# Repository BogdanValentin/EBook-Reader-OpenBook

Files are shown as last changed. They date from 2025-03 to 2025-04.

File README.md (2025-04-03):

# Proiect - OpenBook

## Diagrama Bloc

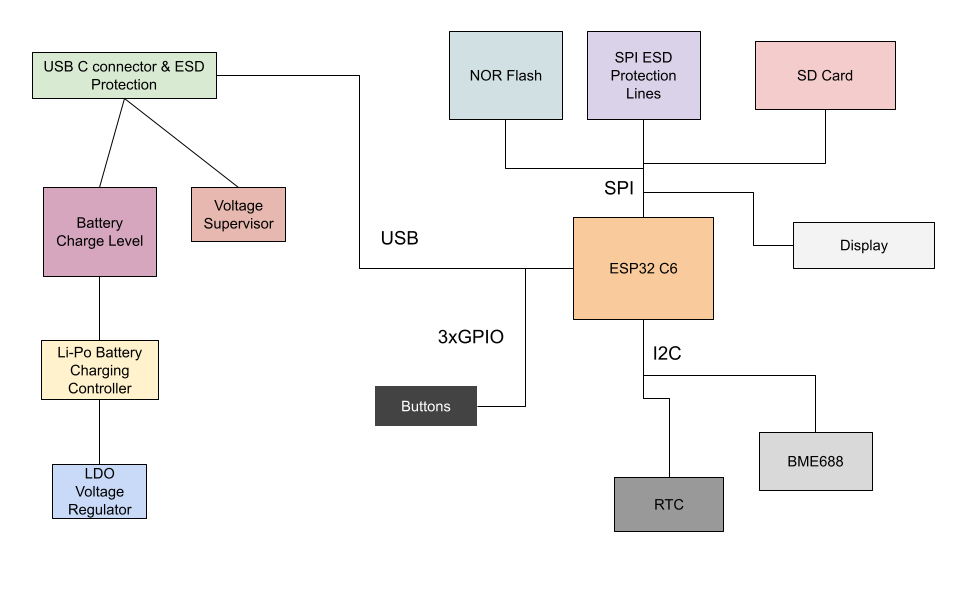
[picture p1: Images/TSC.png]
Diagrama Bloc
  

## Pasii de implementare
Am realizat in primul rand schema electrica propusa pe OCW. Apoi am realizat board-ul avand grija prima data sa tai placa dupa dimensiunile precizate. Am pus componentele pe placa incercand sa urmez designul propus. Am pus cele 2 planuri de masa si am rutat firele. Am creat modelele 3D pt placa, baterie si ecran si le-am asamblat in produsul finit.

## Probleme & decizii luate
Senzorul BME688 nu se afla in biblioteca ci BME680 asa ca l-am folosit pe acela. Apar mai multe erori la conectarea firelor GND to GND, am inteles ca mai multi se confrunta cu aceasta problema asa ca am lasat asa. Mufa USB creaza o eroare Board Outline Clearance care, la fel, am inteles ca este una comuna.

## Bill of Materials (BOM)

| Componenta | Link de Achizitie | Datasheet |
|---|---|---|
| **USB C connector** | [Link](https://ro.mouser.com/ProductDetail/GCT/USB4110-GF-A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) | [Datasheet](https://ro.mouser.com/datasheet/2/837/GCT_USB4110_Product_Drawing___20k_cycles-3455479.pdf) |
| **ESD Protection** | [Link](https://ro.mouser.com/ProductDetail/STMicroelectronics/USBLC6-2SC6Y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) | [Datasheet](https://ro.mouser.com/datasheet/2/389/usblc6_2sc6y-1852505.pdf) |
| **LDO Voltage Regulator** | [Link](https://ro.mouser.com/ProductDetail/Torex-Semiconductor/XC6220A331MR-G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) | [Datasheet](https://ro.mouser.com/datasheet/2/760/xc6220-3371556.pdf) |
| **SD Card** | [Link](https://store.comet.srl.ro/Catalogue/Product/43497/?mark=2) | [Datasheet](https://www.attend.com.tw/data/download/file/112A-TAAR-R03.rar) |
| **ESP32 C6** | [Link](https://ro.mouser.com/ProductDetail/Espressif-Systems/ESP32-C6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) | [Datasheet](https://ro.mouser.com/datasheet/2/891/esp32_c6_datasheet_en-3304070.pdf) |
| **Li-Po Battery Charging Controller**| [Link](https://ro.mouser.com/ProductDetail/Microchip-Technology/MCP73831-2ATI-MC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) | [Datasheet](https://ro.mouser.com/datasheet/2/268/MCP73831_Family_Data_Sheet_DS20001984H-3441711.pdf) | |
| **E-Paper Drive Circuit** | [Link](https://ro.mouser.com/ProductDetail/Vishay-Semiconductors/SI1308EDL-T1-GE3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) | [Datasheet](https://www.vishay.com/doc?63399) |
| **E-Paper Display Header** | [Link](https://ro.mouser.com/ProductDetail/Hirose-Connector/FH34SRJ-24S-0.5SH99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) | [Datasheet](https://ro.mouser.com/datasheet/2/185/FH34SRJ_24S_0_5SH_99__CL0580_1255_6_99_2DDrawing_0-1615044.pdf) |
| **EPD Power** | [Link](https://ro.mouser.com/ProductDetail/Diodes-Incorporated/DMG2305UX-7?qs=L1DZKBg7t5F%2FNBHrjfxC%252Bg%3D%3D) | [Datasheet](https://www.diodes.com/assets/Datasheets/DMG2305UX.pdf) |
| **Environmental Sensor BME688** | [Link](https://ro.mouser.com/ProductDetail/Bosch-Sensortec/BME688?qs=IS%252B4QmGtzzqQoVDscqwx3A%3D%3D) | [Datasheet](https://ro.mouser.com/datasheet/2/783/bst_bme688_fl000-2307034.pdf) |
| **Voltage Supervisor** | [Link](https://ro.mouser.com/ProductDetail/ROHM-Semiconductor/BD5229G-TR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) | [Datasheet](https://fscdn.rohm.com/en/products/databook/datasheet/ic/power/voltage_detector/bd52xxg-e.pdf) |
| **Battery Charge Level** | [Link](https://ro.mouser.com/ProductDetail/Analog-Devices-Maxim-Integrated/MAX17048G+T10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) | [Datasheet](https://ro.mouser.com/datasheet/2/609/MAX17048_MAX17049-3469099.pdf) |
| **RTC Module DS3231SN** | [Link](https://ro.mouser.com/ProductDetail/Analog-Devices-Maxim-Integrated/DS3231SNTR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) | [Datasheet](https://ro.mouser.com/datasheet/2/609/DS3231-3421123.pdf) | | |
| **SPI ESD Protection Lines** | [Link](https://ro.mouser.com/ProductDetail/Littelfuse/PGB1010603MR?qs=gu7KAQ731URLg4GSnNNN7Q%3D%3D) | [Datasheet](https://www.littelfuse.com/assetdocs/pulseguard-esd-suppressors-pgb1-datasheet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) |
| **External NORFlash 64MB** | [Link](https://ro.mouser.com/ProductDetail/Winbond/W25Q512JVEIQ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) | [Datasheet](https://ro.mouser.com/datasheet/2/949/Winbond_W25Q512JV_Datasheet-3240039.pdf) |

---

## 3. Descrierea Functionalitatii Hardware

## Componente Folosite:

1. **USB C connector & ESD protection**  
2. **LDO Voltage Regulator**  
3. **SD card**  
4. **ESP32 C6**  
5. **Li-Po Battery Charging Controller**  
6. **Display Type Selector**  
7. **E-Paper Drive Circuit**  
8. **E-Paper Display Header**  
9. **EPD Power**  
10. **Environmental Sensor BME688**  
11. **Voltage Supervisor + Reset & Boot/IO Button**  
12. **Battery ChargeLevel**  
13. **RTC Module DS3231SN**  
14. **Qwiic/Stemma QT**  
15. **Test Pads**  
16. **SPI ESD Protection Lines**  
17. **External NORFlash 64MB**

---

## 4. ESP32-C6 Pini

| Componenta | Pini ESP32 | Rol |
|---|---|---|
| **E-Paper Display** | SPI (MISO, MOSI, CLK, CS) | Afisare |
| **BME688** | I2C (SDA, SCL) | Senzor multirol |
| **RTC DS3231SN** | I2C (SDA, SCL) | Ceas / Temporizare  |
| **Li-Po Battery Controller** | GPIO  | incarcare |
| **SD Card** | SPI (MISO, MOSI, CLK, CS) | Stocare date |
| **Qwiic/Stemma QT** | I2C | -  |

---

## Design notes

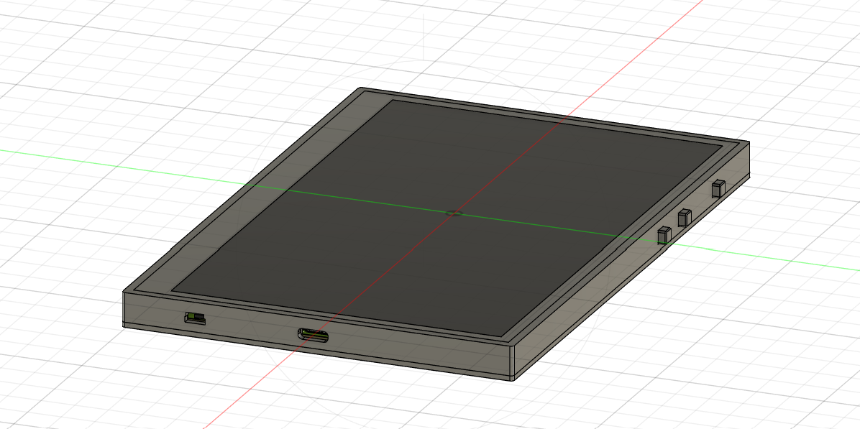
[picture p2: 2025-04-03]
Images/carcasa.png

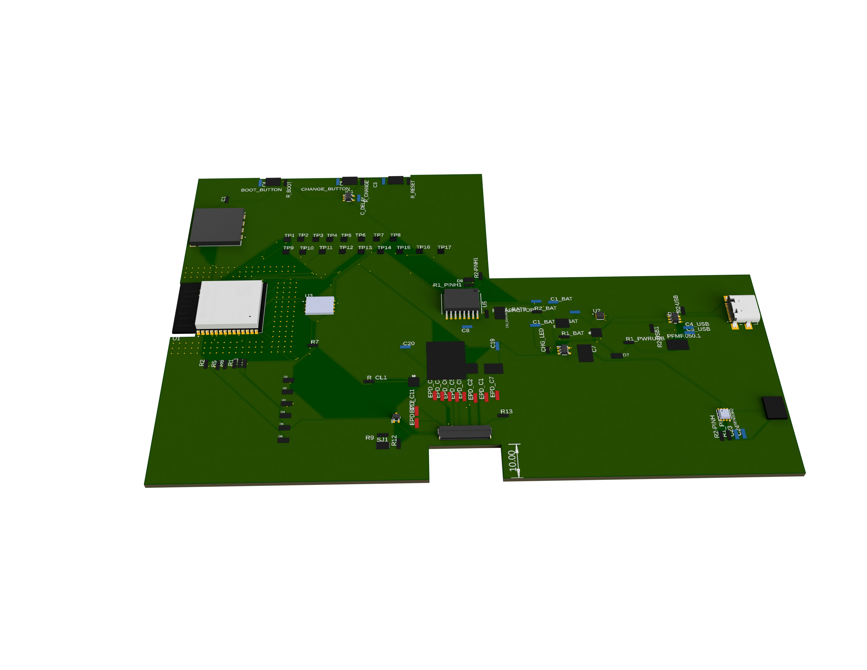
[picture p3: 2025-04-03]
Images/pcb.PNG

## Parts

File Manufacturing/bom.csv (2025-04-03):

Qty | Value | Device | Package | Parts | Description | ARROW_PART_NUMBER | ARROW_PRICE-STOCK | AVAILABILITY | CENTROID_NOT_SPECIFIED | CHECK_PRICES | COPYRIGHT | DATASHEET | DESCRIPTION | DIGIKEY_DESCRIPTION | DIGIKEY_PART_NUMBER | HEIGHT | LEAD_FREE | MANUFACTURER_NAME | MANUFACTURER_PART_NUMBER | MF | MFR_NAME | MOUSER_PART_NUMBER | MOUSER_PRICE-STOCK | MOUSER_TESTING_PART_NUMBER | MOUSER_TESTING_PRICE-STOCK | MP | MPN | PACKAGE | POPULARITY | PREFIX | PRICE | PROD_ID | PURCHASE-URL | ROHS | SNAPEDA_LINK | SPICEMODEL | SPICEPREFIX | TEMPERATURE_RANGE_HIGH | TEMPERATURE_RANGE_LOW | TP_SIGNAL_NAME | VALUE
1 |  | ADAFRUIT_LEDCHIP-LED0603 | ADAFRUIT_CHIP-LED0603 | CHG_LED | LED
3 |  | BUTTON_CUSYOMV1 | MYBUTTON | BOOT_BUTTON, CHANGE_BUTTON, RESET_BUTTON
1 |  | ESP32_WROVER_EAGLE-LTSPICE_RR0402 | ESP32_WROVER_EAGLE-LTSPICE_R0402 | R9 | RESISTOR, European symbol |  |  |  |  |  |  |  |  |  |  |  |  |  |  |  |  |  |  |  |  |  |  |  |  |  |  |  |  |  |  | NONE | R
1 |  | SJ | SJ | SJ1 | SMD solder JUMPER |  |  |  |  |  |  |  |  |  |  |  |  |  |  |  |  |  |  |  |  |  |  |  | 3
1 | 0.47 | ESP32_WROVER_EAGLE-LTSPICE_RR0402 | ESP32_WROVER_EAGLE-LTSPICE_R0402 | R12 | RESISTOR, European symbol |  |  |  |  |  |  |  |  |  |  |  |  |  |  |  |  |  |  |  |  |  |  |  |  |  |  |  |  |  |  | NONE | R
1 | 100K | ESP32_WROVER_EAGLE-LTSPICE_RR0402 | ESP32_WROVER_EAGLE-LTSPICE_R0402 | R1_PWRUSB | RESISTOR, European symbol |  |  |  |  |  |  |  |  |  |  |  |  |  |  |  |  |  |  |  |  |  |  |  |  |  |  |  |  |  |  | NONE | R
8 | 100nF | EAGLE-LTSPICE_CC0402 | EAGLE-LTSPICE_C0402 | C1, C4, C4_USB, C5, C8, C23, C24, C_DELAY | CAPACITOR, European symbol |  |  |  |  |  |  |  |  |  |  |  |  |  |  |  |  |  |  |  |  |  |  |  |  |  |  |  |  |  |  | NONE | C
1 | 100uF TANT | RCL_CPOL-EUCT3528 | RCL_CT3528 | C7 | POLARIZED CAPACITOR, European symbol |  |  |  |  |  |  |  |  |  |  |  |  |  |  |  |  |  |  |  |  |  |  |  | 0 |  |  |  |  |  |  |  | C
13 | 10K | ESP32_WROVER_EAGLE-LTSPICE_RR0402 | ESP32_WROVER_EAGLE-LTSPICE_R0402 | R1, R1_PINH, R2, R2-PINH, R3, R4, R5, R6, R7, R13, R_BOOT, R_CL1, R_RESET | RESISTOR, European symbol |  |  |  |  |  |  |  |  |  |  |  |  |  |  |  |  |  |  |  |  |  |  |  |  |  |  |  |  |  |  | NONE | R
3 | 10k | ESP32_WROVER_EAGLE-LTSPICE_RR0402 | ESP32_WROVER_EAGLE-LTSPICE_R0402 | R1_PINH1, R2-PINH1, R_CHANGE | RESISTOR, European symbol |  |  |  |  |  |  |  |  |  |  |  |  |  |  |  |  |  |  |  |  |  |  |  |  |  |  |  |  |  |  | NONE | R
1 | 10uF | EAGLE-LTSPICE_CC0402 | EAGLE-LTSPICE_C0402 | C20 | CAPACITOR, European symbol |  |  |  |  |  |  |  |  |  |  |  |  |  |  |  |  |  |  |  |  |  |  |  |  |  |  |  |  |  |  | NONE | C
1 | 112A-TAAR-R03_ATTEND | 112A-TAAR-R03_ATTEND | 112ATAARR03ATTEND | J1 | Micro SD Card Socket, Push-Push Type, Top Mount, SMT, H=1.83mm, 10u |  |  |  |  |  |  |  | Micro SD Card Socket | Push-Push Type | Top Mount | SMT | H=1.83mm | 10u |  |  | 1.9mm |  | ATTEND | 112A-TAAR-R03 ATTEND
1 | 15 | ESP32_WROVER_EAGLE-LTSPICE_RR0402 | ESP32_WROVER_EAGLE-LTSPICE_R0402 | R_CAPACITOR | RESISTOR, European symbol |  |  |  |  |  |  |  |  |  |  |  |  |  |  |  |  |  |  |  |  |  |  |  |  |  |  |  |  |  |  | NONE | R
1 | 1uF | EAGLE-LTSPICE_CC0402 | EAGLE-LTSPICE_C0402 | C3 | CAPACITOR, European symbol |  |  |  |  |  |  |  |  |  |  |  |  |  |  |  |  |  |  |  |  |  |  |  |  |  |  |  |  |  |  | NONE | C
10 | 1uF/50V | EAGLE-LTSPICE_CC0402 | EAGLE-LTSPICE_C0402 | EPD_C1, EPD_C2, EPD_C5, EPD_C6, EPD_C7, EPD_C8, EPD_C9, EPD_C10, EPD_C11, EPD_C12 | CAPACITOR, European symbol |  |  |  |  |  |  |  |  |  |  |  |  |  |  |  |  |  |  |  |  |  |  |  |  |  |  |  |  |  |  | NONE | C
1 | 200 | ESP32_WROVER_EAGLE-LTSPICE_RR0402 | ESP32_WROVER_EAGLE-LTSPICE_R0402 | R1_BAT | RESISTOR, European symbol |  |  |  |  |  |  |  |  |  |  |  |  |  |  |  |  |  |  |  |  |  |  |  |  |  |  |  |  |  |  | NONE | R
2 | 20V/4.2A/52mO/1.4W | ESP32_WROVER_SPARKFUN-DISCRETESEMI_MOSFET_PCH-DMG2305UX-7 | ESP32_WROVER_SPARKFUN-DISCRETESEMI_SOT23-3 | Q1, Q2 | P-channel MOSFETs |  |  |  |  |  |  |  |  |  |  |  |  |  |  |  |  |  |  |  |  |  |  |  |  |  |  | TRAN-14388 |  |  |  |  |  |  |  |  | 20V/4.2A/52mO/1.4W
1 | 2K | ESP32_WROVER_EAGLE-LTSPICE_RR0402 | ESP32_WROVER_EAGLE-LTSPICE_R0402 | R2_BAT | RESISTOR, European symbol |  |  |  |  |  |  |  |  |  |  |  |  |  |  |  |  |  |  |  |  |  |  |  |  |  |  |  |  |  |  | NONE | R
4 | 4.7uF | EAGLE-LTSPICE_CC0402 | EAGLE-LTSPICE_C0402 | C1_BAT, C1_BAT1, C1_BAT2, C5_USB | CAPACITOR, European symbol |  |  |  |  |  |  |  |  |  |  |  |  |  |  |  |  |  |  |  |  |  |  |  |  |  |  |  |  |  |  | NONE | C
1 | 4.7uF | EAGLE-LTSPICE_CC0402 | EAGLE-LTSPICE_C0402 | C2_BAT | CAPACITOR, European symbol |  |  |  |  |  |  |  |  |  |  |  |  |  |  |  |  |  |  |  |  |  |  |  |  |  |  |  |  |  |  | NONE | C
1 | 4.7uF/25V | EAGLE-LTSPICE_CC0402 | EAGLE-LTSPICE_C0402 | C19 | CAPACITOR, European symbol |  |  |  |  |  |  |  |  |  |  |  |  |  |  |  |  |  |  |  |  |  |  |  |  |  |  |  |  |  |  | NONE | C
2 | 5k1 | ESP32_WROVER_EAGLE-LTSPICE_RR0402 | ESP32_WROVER_EAGLE-LTSPICE_R0402 | R2-USB, R2-USB1 | RESISTOR, European symbol |  |  |  |  |  |  |  |  |  |  |  |  |  |  |  |  |  |  |  |  |  |  |  |  |  |  |  |  |  |  | NONE | R
1 | 68uH | 744043680IND_4828-WE-TPC_WRE | IND_4828-WE-TPC_WRE | L1 |  |  |  |  |  |  | Copyright (C) 2024 Ultra Librarian. All rights reserved. |  |  |  |  |  |  |  | 744043680 |  | Wurth Electronics
1 | BD5229G-TR | BD5229G-TR | SOT95P280X125-5N | IC1 | Voltage Detector with Adjustable Delay Time: CMOS processes are utilized to develop high precision, low current consumption CMOS reset ICs that allow arbitrary setting of the delay time. The extensive lineup includes both Nch Open Drain and CMOS output types in a wide range of detection voltages (from 2.3V to 6.0V, in 0.1V steps), enabling selection of the ideal solution based on customer requirements. In addition, the entire series is of course both lead-free and RoHS-compliant. |  |  |  |  |  |  |  | Voltage Detector with Adjustable Delay Time: CMOS processes are utilized to develop high precision | low current consumption CMOS reset ICs that allow arbitrary setting of the delay time. The extensive lineup includes both Nch Open Drain and CMOS output types in a wide range of detection voltages (from 2.3V to 6.0V | in 0.1V steps) | enabling selection of the ideal solution based on customer requirements. In addition | the entire series is of course both lead-free and RoHS-compliant. |  |  | 1.25mm |  | ROHM Semiconductor | BD5229G-TR |  |  | 755-BD5229G-TR | https://www.mouser.co.uk/ProductDetail/ROHM-Semiconductor/BD5229G-TR?qs=4kLU8WoGk0vvnhrrYwdszw%3D%3D
1 | CPH3225A | CPH3225A | CAPCP3225X100N | C10_SUPERCAP | Cap 0.011F 3.3V 1210 Flat Check availability |  |  | Not in stock |  | https://www.snapeda.com/parts/CPH3225A/Seiko+Instruments/view-part/?ref=eda |  |  | 11 mF (EDLC) Supercapacitor 3.3 V 1210 (3225 Metric) - - |  |  |  |  |  |  | Seiko Instruments |  |  |  |  |  | CPH3225A |  | 1210 Seiko |  |  | None |  | https://www.snapeda.com/api/url_track_click_mouser/?unipart_id=562593&manufacturer=Seiko Instruments&part_name=CPH3225A&search_term=None |  | https://www.snapeda.com/parts/CPH3225A/Seiko+Instruments/view-part/?ref=snap
1 | DS3231SN# | DS3231SN# | SOIC127P1032X265-16N | U5 | Real Time Clock Serial 16-Pin SOIC W T/R Check availability |  |  | In Stock |  | https://www.snapeda.com/parts/DS3231SN%23/Analog+Devices/view-part/?ref=eda |  |  | Extremely Accurate I²C-Integrated RTC/TCXO/Crystal |  |  |  |  |  |  | Analog Devices |  |  |  |  |  | DS3231SN# |  | SOIC-16 Maxim |  |  | None |  | https://www.snapeda.com/api/url_track_click_mouser/?unipart_id=99048&manufacturer=Analog Devices&part_name=DS3231SN#&search_term=None |  | https://www.snapeda.com/parts/DS3231SN%23/Analog+Devices/view-part/?ref=snap
1 | ESP32-C6-WROOM-1-N8 | ESP32-C6-WROOM-1-N8 | XCVR_ESP32-C6-WROOM-1-N8 | U1 | Check availability |  |  | In Stock |  | https://www.snapeda.com/parts/ESP32-C6-WROOM-1-N8/Espressif+Systems/view-part/?ref=eda |  |  | Multiprotocol Modules ESP32-C6 module | Wi-Fi 6 in 2.4 GHz band | Bluetooth 5 | Zigbee 3.0 and Thread. ESP34-WROOM Compatible - ENGINEERING SAMPLE |  |  |  |  |  |  | Espressif Systems |  |  |  |  |  | ESP32-C6-WROOM-1-N8 |  | None |  |  | None |  |  |  | https://www.snapeda.com/parts/ESP32-C6-WROOM-1-N8/Espressif+Systems/view-part/?ref=snap
1 | ESP32C6_VARISTORCN1812 | ESP32C6_VARISTORCN1812 | ESP32C6_VARISTOR_CT/CN1812 | PFMF.050.1 | VARISTOR |  |  |  |  |  |  |  |  |  |  |  |  |  |  |  |  |  |  |  |  |  |  |  | 0
2 | ESP32_WROVER_AVX---SD0805S020S1R0_AVX_SD0805S020S1R0_0_0AVX_SD0805S020S1R0_0_0 | ESP32_WROVER_AVX---SD0805S020S1R0_AVX_SD0805S020S1R0_0_0AVX_SD0805S020S1R0_0_0 | ESP32_WROVER_AVX---SD0805S020S1R0_AVX_SD0805S020S1R0_0 | D7, D8 | Schottky Barrier Rectifier Diode |  |  |  | No |  |  | http://datasheets.avx.com/schottky.pdf |  | DIODE SCHOTTKY 20V 1A 0805 | 478-7800-1-ND |  | yes |  |  | AVX |  | 581-SD0805S020S1R0 |  |  |  |  |  | 0805 (2012 metric) |  | D |  |  |  | yes |  |  |  | +125°C | -55°C
1 | ESP32_WROVER_BME680_BME680 | ESP32_WROVER_BME680_BME680 | ESP32_WROVER_BME680_PSON80P300X300X100-8N | SENSOR2 | Integrated Environmental Unit |  |  | Unavailable |  |  |  |  | Integrated Environmental Unit |  |  |  |  |  |  | Bosch Sensortec |  |  |  |  |  | BME680 |  | LGA-8 Bosch Tools |  |  | None
1 | ESP32_WROVER_SPARKFUN-IC-POWER_MCP73831 | ESP32_WROVER_SPARKFUN-IC-POWER_MCP73831 | ESP32_WROVER_SPARKFUN-IC-POWER_SOT23-5 | U4 | MCP73831T Li-Ion, Li-Pol Controller |  |  |  |  |  |  |  |  |  |  |  |  |  |  |  |  |  |  |  |  |  |  |  |  |  |  | IC-09995
1 | FH34SRJ-24S-0.5SH_99_ | FH34SRJ-24S-0.5SH_99_ | FH34SRJ24S05SH99 | J3 | (0.50mm) Surface Mount, Right Angle |  |  |  |  |  |  |  | 24 Position FFC | FPC Connector Contacts | (0.50mm) Surface Mount | Right Angle |  |  | 1.1mm |  | Hirose | FH34SRJ-24S-0.5SH(99) |  |  | 798-FH34SRJ24S05SH99 | https://www.mouser.co.uk/ProductDetail/Hirose-Connector/FH34SRJ-24S-0.5SH99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
1 | MAX17048G+T10 | MAX17048G+T10 | SON50P200X200X80-9N | U2 | Check availability |  |  | In Stock |  | https://www.snapeda.com/parts/MAX17048G+T10/Analog+Devices/view-part/?ref=eda |  |  | 3µA 1-Cell/2-Cell Fuel Gauge with ModelGauge |  |  |  |  |  |  | Analog Devices |  |  |  |  |  | MAX17048G+T10 |  | TDFN-8 Maxim |  |  | None |  | https://www.snapeda.com/api/url_track_click_mouser/?unipart_id=329239&manufacturer=Analog Devices&part_name=MAX17048G+T10&search_term=None |  | https://www.snapeda.com/parts/MAX17048G+T10/Analog+Devices/view-part/?ref=snap
3 | MBR0530 | MBR0530 | SOD3716X135N | D9, D10, D11 | ON SEMICONDUCTOR - MBR0530 - DIODE, SCHOTTKY, 0.5A, 30V, SOD-123 |  |  | In Stock |  | https://www.snapeda.com/parts/MBR0530/Onsemi/view-part/?ref=eda |  |  | Diode Schottky 30 V 500mA Surface Mount SOD-123 |  |  |  |  |  |  | ON Semiconductor |  |  |  |  |  | MBR0530 |  | SOD-123-2 ON Semiconductor |  |  | None |  | https://www.snapeda.com/api/url_track_click_mouser/?unipart_id=179458&manufacturer=ON Semiconductor&part_name=MBR0530&search_term=None |  | https://www.snapeda.com/parts/MBR0530/Onsemi/view-part/?ref=snap
6 | PGB1010603MR | PGB1010603MR | DIOC1608X36N | D1, D2, D3, D4, D5, D6 | Check availability |  |  | In Stock |  | https://www.snapeda.com/parts/PGB1010603MR/Littelfuse/view-part/?ref=eda |  |  | 150V (Typ) Clamp - Ipp Tvs Diode Surface Mount 0603 (1608 Metric) |  |  |  |  |  |  | Littelfuse Inc. |  |  |  |  |  | PGB1010603MR |  | 0603 Littelfuse Inc. |  |  | None |  | https://www.snapeda.com/api/url_track_click_mouser/?unipart_id=5659453&manufacturer=Littelfuse Inc.&part_name=PGB1010603MR&search_term=None |  | https://www.snapeda.com/parts/PGB1010603MR/Littelfuse/view-part/?ref=snap
1 | QWIIC_RIGHT_ANGLE | QWIIC_CONNECTORJS-1MM | JST04_1MM_RA | J2 | SparkFun I2C Standard Qwiic Connector |  |  |  |  |  |  |  |  |  |  |  |  |  |  |  |  |  |  |  |  |  |  |  |  |  |  | CONN-13694 |  |  |  |  |  |  |  |  | QWIIC_RIGHT_ANGLE
1 | SAMACSYS_PARTS_USB4110-GF-A | SAMACSYS_PARTS_USB4110-GF-A | SAMACSYS_PARTS_USB4110GFA | J4 | CONN USB 2.0 TYPE-C R/A SMT |  |  |  |  |  |  |  | CONN USB 2.0 TYPE-C R/A SMT |  |  | 3.26mm |  | GCT (GLOBAL CONNECTOR TECHNOLOGY) | USB4110-GF-A |  |  | 640-USB4110-GF-A | https://www.mouser.co.uk/ProductDetail/GCT/USB4110-GF-A?qs=KUoIvG%2F9IlYiZvIXQjyJeA%3D%3D
1 | SI1308EDL-T1-GE3 | SI1308EDL-T1-GE3 | SOT65P210X110-3N | Q3 | MOSFET N-Ch 30V 1.5A TrenchFET SC70 Vishay Si1308EDL-T1-GE3 N-channel MOSFET Transistor, 1.5 A, 30 V, 3-Pin SC-70 |  |  | In Stock |  | https://www.snapeda.com/parts/SI1308EDL-T1-GE3/Vishay+Siliconix/view-part/?ref=eda |  |  | Si1308EDL-T1-GE3 N-channel MOSFET Transistor | 1.5 A | 30 V | 3-Pin SC-70 | Siliconix / Vishay SI1308EDL-T1-GE3 |  |  |  |  |  |  | Vishay Siliconix |  |  |  |  |  | SI1308EDL-T1-GE3 |  | SOT-323 Vishay Semiconductor |  |  | None |  | https://www.snapeda.com/api/url_track_click_mouser/?unipart_id=274603&manufacturer=Vishay Siliconix&part_name=SI1308EDL-T1-GE3&search_term=None |  | https://www.snapeda.com/parts/SI1308EDL-T1-GE3/Vishay+Siliconix/view-part/?ref=snap
17 | TPTP20R | TPTP20R | TP20R | TP1, TP2, TP3, TP4, TP5, TP6, TP7, TP8, TP9, TP10, TP11, TP12, TP13, TP14, TP15, TP16, TP17 | Test pad |  |  |  |  |  |  |  |  |  |  |  |  |  |  |  |  |  |  |  |  |  |  |  | 2
1 | USBLC6-2SC6Y | USBLC6-2SC6Y | SOT95P280X145-6N | D12 | Low Cap. ESD Protection Auto SOT-23-6 STMicroelectronics USBLC6-2SC6Y, Dual Uni-Directional TVS Diode Array, 6-Pin SOT-23 |  |  | In Stock |  | https://www.snapeda.com/parts/USBLC6-2SC6Y/STMicroelectronics/view-part/?ref=eda |  |  | 17V Clamp 5A (8/20µs) Ipp Tvs Diode Surface Mount SOT-23-6 |  |  |  |  |  |  | STMicroelectronics |  |  |  |  |  | USBLC6-2SC6Y |  | SOT-23-6 STMicroelectronics |  |  | None |  |  |  | https://www.snapeda.com/parts/USBLC6-2SC6Y/STMicroelectronics/view-part/?ref=snap
1 | W25Q512JVEIQ | W25Q512JVEIQ | SON127P600X800X80-9N | U3 | Check availability |  |  | In Stock |  | https://www.snapeda.com/parts/W25Q512JVEIQ/Winbond+Electronics/view-part/?ref=eda |  |  | FLASH - NOR Memory IC 512Mb (64M x 8) SPI - Quad I/O 133 MHz 8-WSON (8x6) |  |  |  |  |  |  | Winbond Electronics |  |  |  |  |  | W25Q512JVEIQ |  | Package |  |  | None |  |  |  | https://www.snapeda.com/parts/W25Q512JVEIQ/Winbond+Electronics/view-part/?ref=snap
1 | XC6220A331MR-G | XC6220A331MR-G | SOT95P280X120-5N | IC2 | LDO Voltage Regulators |  |  |  |  |  |  |  | LDO Voltage Regulators |  |  | 1.2mm |  | Torex | XC6220A331MR-G |  |  | 865-XC6220A331MR-G | https://www.mouser.co.uk/ProductDetail/Torex-Semiconductor/XC6220A331MR-G?qs=AsjdqWjXhJ8ZSWznL1J0gg%3D%3D

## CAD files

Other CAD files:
Mechanical/OpenBook Enclosure v7.f3z

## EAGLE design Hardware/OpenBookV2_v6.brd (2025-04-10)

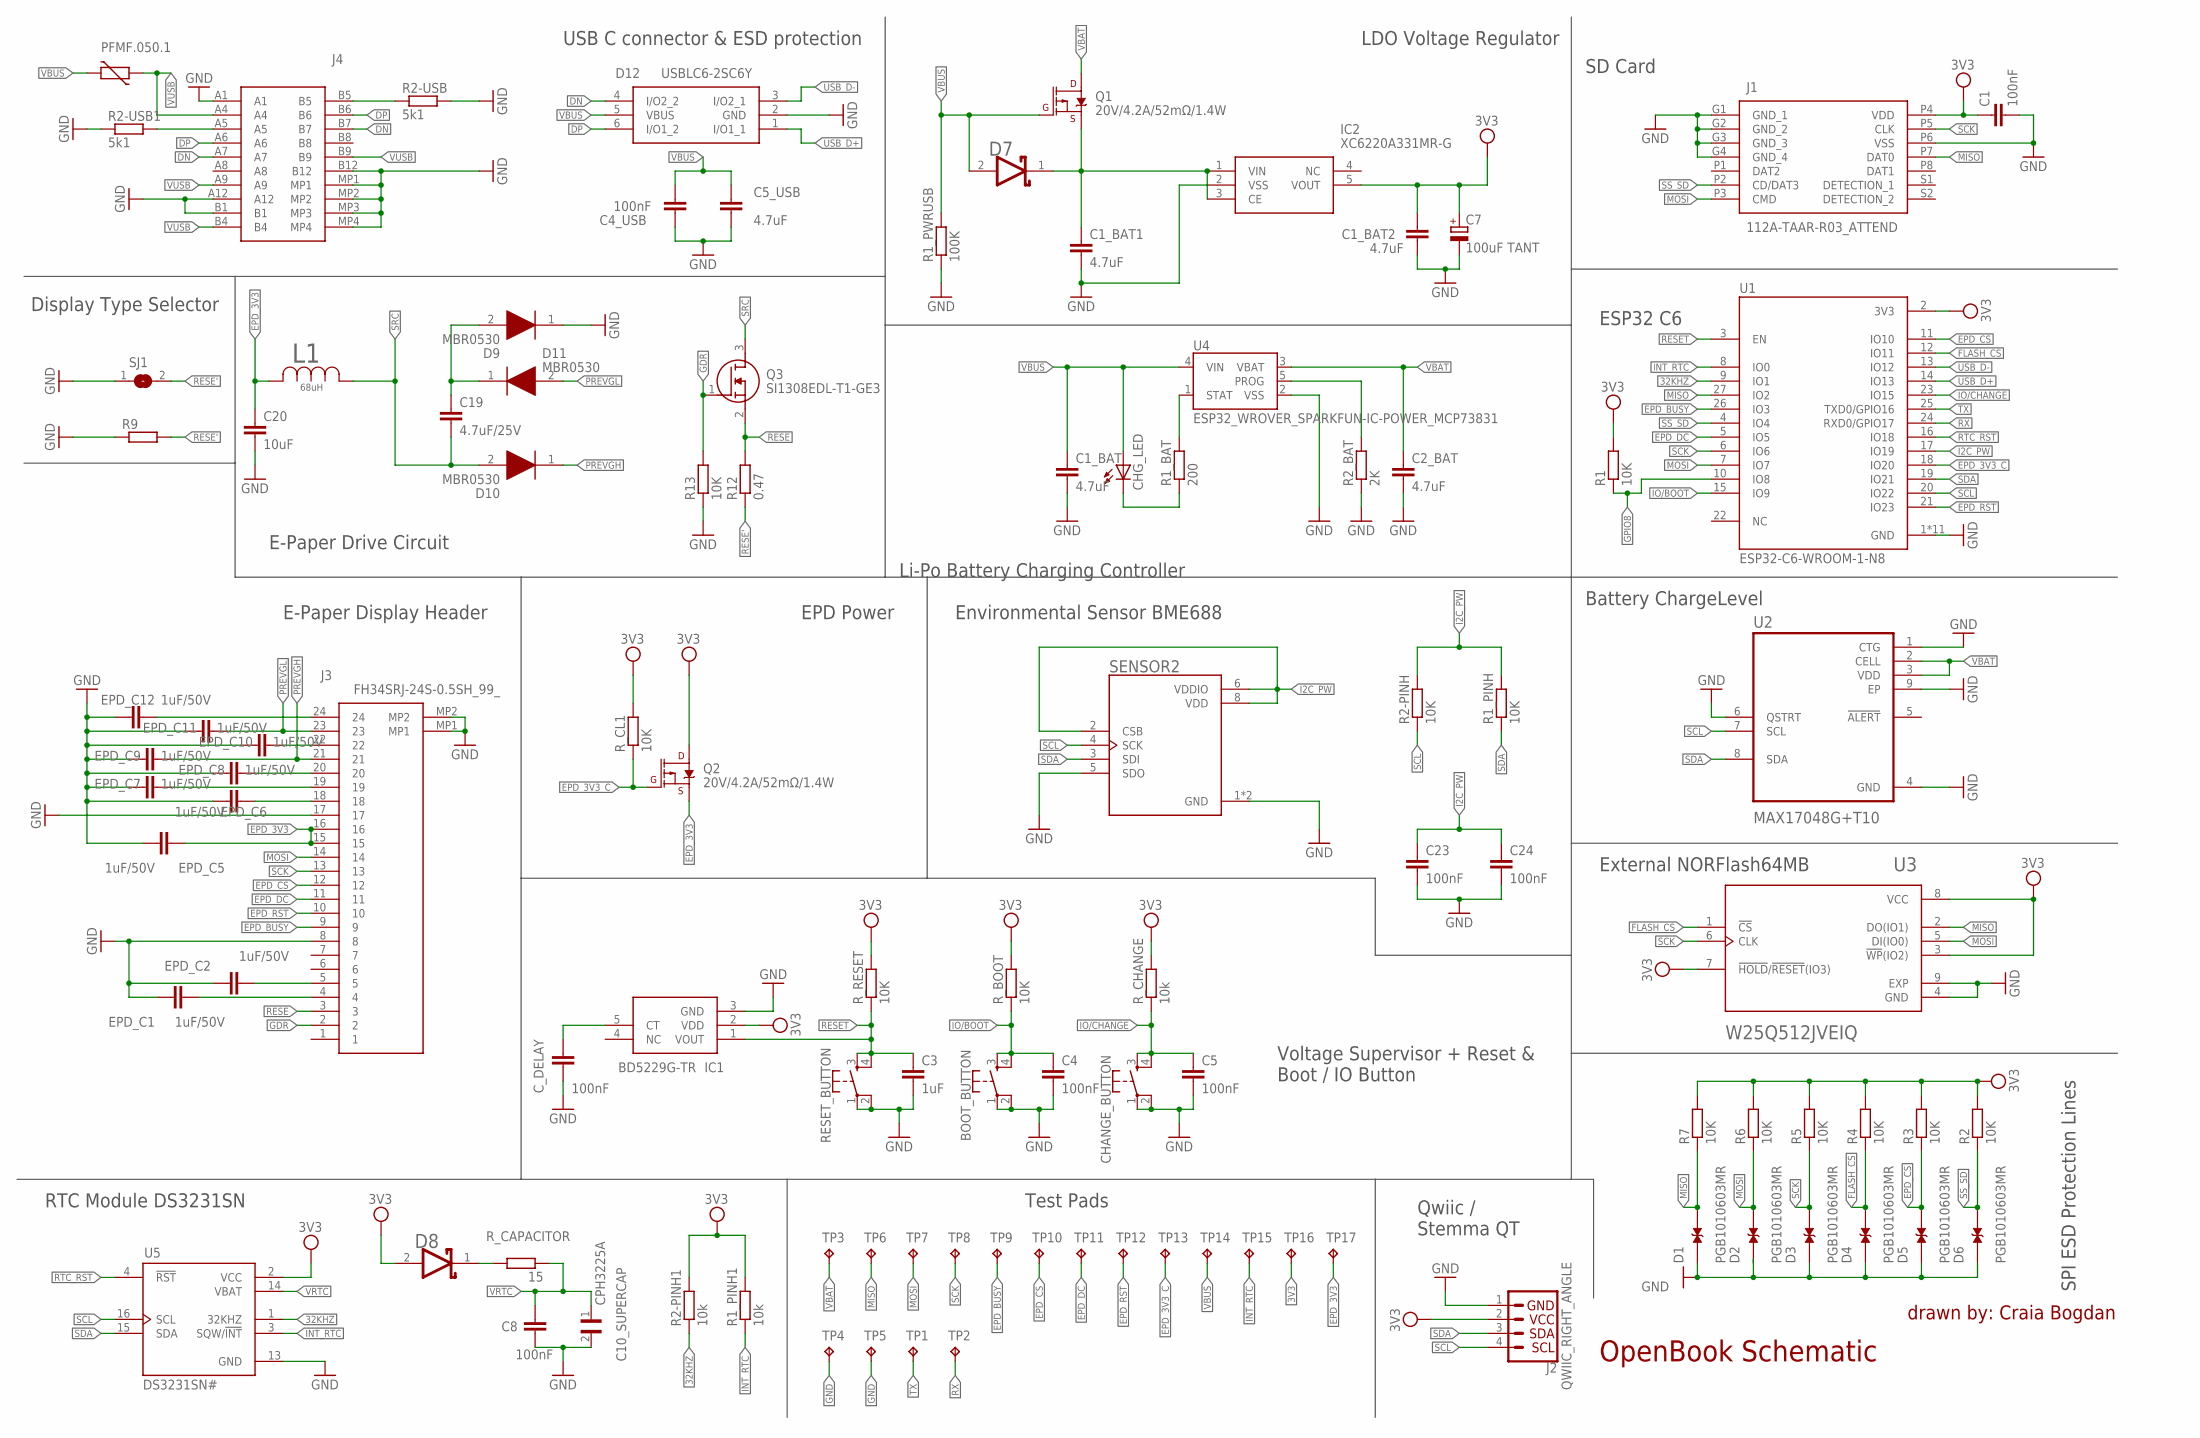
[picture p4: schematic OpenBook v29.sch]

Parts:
BOOT_BUTTON: BUTTON_CUSYOMV1; MYBUTTON
C1, C4, C4_USB, C5, C8, C23, C24: 100nF; EAGLE-LTSPICE_C0402
C1_BAT, C1_BAT1, C1_BAT2, C2_BAT, C5_USB: 4.7uF; EAGLE-LTSPICE_C0402
C3: 1uF; EAGLE-LTSPICE_C0402
C7: 100uF TANT; RCL_CT3528
C10_SUPERCAP: CPH3225A; CAPCP3225X100N
C19: 4.7uF/25V; EAGLE-LTSPICE_C0402
C20: 10uF; EAGLE-LTSPICE_C0402
CHANGE_BUTTON: BUTTON_CUSYOMV1; MYBUTTON
CHG_LED: ADAFRUIT_LEDCHIP-LED0603; ADAFRUIT_CHIP-LED0603
C_DELAY: 100nF; EAGLE-LTSPICE_C0402
D1, D2, D3, D4, D5, D6: PGB1010603MR; DIOC1608X36N
D7, D8: ESP32_WROVER_AVX---SD0805S020S1R0_AVX_SD0805S020S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; ESP32_WROVER_AVX---SD0805S020S1R0_AVX_SD0805S020S1R0_0
D9, D10, D11: MBR0530; SOD3716X135N
D12: USBLC6-2SC6Y; SOT95P280X145-6N
EPD_C1, EPD_C2, EPD_C5, EPD_C6, EPD_C7, EPD_C8, EPD_C9, EPD_C10, EPD_C11, EPD_C12: 1uF/50V; EAGLE-LTSPICE_C0402
IC1: BD5229G-TR; SOT95P280X125-5N
IC2: XC6220A331MR-G; SOT95P280X120-5N
J1: 112A-TAAR-R03_ATTEND; 112ATAARR03ATTEND
J2: QWIIC_RIGHT_ANGLE; JST04_1MM_RA
J3: FH34SRJ-24S-0.5SH_99_; FH34SRJ24S05SH99
J4: SAMACSYS_PARTS_USB4110-GF-A; SAMACSYS_PARTS_USB4110GFA
L1: 68uH; IND_4828-WE-TPC_WRE
PFMF.050.1: ESP32C6_VARISTORCN1812; ESP32C6_VARISTOR_CT/CN1812
Q1, Q2: 20V/4.2A/52mΩ/1.4W; ESP32_WROVER_SPARKFUN-DISCRETESEMI_SOT23-3
Q3: SI1308EDL-T1-GE3; SOT65P210X110-3N
R1, R1_PINH, R2, R2-PINH, R3, R4, R5, R6, R7, R13: 10K; ESP32_WROVER_EAGLE-LTSPICE_R0402
R1_BAT: 200; ESP32_WROVER_EAGLE-LTSPICE_R0402
R1_PINH1, R2-PINH1: 10k; ESP32_WROVER_EAGLE-LTSPICE_R0402
R1_PWRUSB: 100K; ESP32_WROVER_EAGLE-LTSPICE_R0402
R2-USB, R2-USB1: 5k1; ESP32_WROVER_EAGLE-LTSPICE_R0402
R2_BAT: 2K; ESP32_WROVER_EAGLE-LTSPICE_R0402
R9: ESP32_WROVER_EAGLE-LTSPICE_RR0402; ESP32_WROVER_EAGLE-LTSPICE_R0402
R12: 0.47; ESP32_WROVER_EAGLE-LTSPICE_R0402
RESET_BUTTON: BUTTON_CUSYOMV1; MYBUTTON
R_BOOT: 10K; ESP32_WROVER_EAGLE-LTSPICE_R0402
R_CAPACITOR: 15; ESP32_WROVER_EAGLE-LTSPICE_R0402
R_CHANGE: 10k; ESP32_WROVER_EAGLE-LTSPICE_R0402
R_CL1: 10K; ESP32_WROVER_EAGLE-LTSPICE_R0402
R_RESET: 10K; ESP32_WROVER_EAGLE-LTSPICE_R0402
SENSOR2: ESP32_WROVER_BME680_BME680; ESP32_WROVER_BME680_PSON80P300X300X100-8N
SJ1: SJ
TP1, TP2, TP3, TP4, TP5, TP6, TP7, TP8, TP9, TP10, TP11, TP12, TP13, TP14, TP15, TP16, TP17: TPTP20R; TP20R
U1: ESP32-C6-WROOM-1-N8; XCVR_ESP32-C6-WROOM-1-N8
U2: MAX17048G+T10; SON50P200X200X80-9N
U3: W25Q512JVEIQ; SON127P600X800X80-9N
U4: ESP32_WROVER_SPARKFUN-IC-POWER_MCP73831; ESP32_WROVER_SPARKFUN-IC-POWER_SOT23-5
U5: DS3231SN#; SOIC127P1032X265-16N

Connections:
3V3: C1.1, C1_BAT2.1, C7.+, D8.2 (ANODE), IC1.2 (VDD), IC2.5 (VOUT), J1.P4 (VDD), J2.2, Q2.3 (D), R1.2, R1_PINH1.2, R2.2, R2-PINH1.2, R3.2, R4.2, R5.2, R6.2, R7.2, R_BOOT.2, R_CHANGE.2, R_CL1.2, R_RESET.2, TP16.TP, U1.2 (3V3), U3.3 (!WP!(IO2)), U3.7 (!HOLD!/!RESET!(IO3)), U3.8 (VCC), U5.2 (VCC)
32KHZ: R2-PINH1.1, U1.9 (IO1), U5.1 (32KHZ)
DN: D12.4 (I/O2_2), J4.A7, J4.B7
DP: D12.6 (I/O1_2), J4.A6, J4.B6
EPD_3V3: C20.1, EPD_C5.2, J3.15, J3.16, L1.2, Q2.2 (S), TP17.TP
EPD_3V3_C: Q2.1 (G), R_CL1.1, TP13.TP, U1.18 (IO20)
EPD_BUSY: J3.9, TP9.TP, U1.26 (IO3)
EPD_CS: D5.2, J3.12, R3.1, TP10.TP, U1.11 (IO10)
EPD_DC: J3.11, TP11.TP, U1.5 (IO5)
EPD_RST: J3.10, TP12.TP, U1.21 (IO23)
FLASH_CS: D4.2, R4.1, U1.12 (IO11), U3.1 (!CS)
GDR: J3.2, Q3.1 (G), R13.2
GND: BOOT_BUTTON.1, BOOT_BUTTON.2, C1.2, C1_BAT.2, C1_BAT1.2, C1_BAT2.2, C2_BAT.2, C3.2, C4.2, C4_USB.2, C5.2, C5_USB.2, C7.-, C8.2, C10_SUPERCAP.2, C20.2, C23.2, C24.2, CHANGE_BUTTON.1, CHANGE_BUTTON.2, C_DELAY.2, D1.1, D2.1, D3.1, D4.1, D5.1, D6.1, D9.1 (K), D12.2 (GND), EPD_C1.1, EPD_C2.1, EPD_C5.1, EPD_C6.1, EPD_C7.1, EPD_C8.1, EPD_C9.1, EPD_C10.1, EPD_C11.1, EPD_C12.1, IC1.3 (GND), IC2.2 (VSS), J1.G1 (GND_1), J1.G2 (GND_2), J1.G3 (GND_3), J1.G4 (GND_4), J1.P6 (VSS), J2.1, J3.8, J3.17, J3.MP1, J3.MP2, J4.A1, J4.A12, J4.B1, J4.B12, J4.MP1, J4.MP2, J4.MP3, J4.MP4, R1_PWRUSB.1, R2-USB.2, R2-USB1.1, R2_BAT.1, R9.1, R13.1, RESET_BUTTON.1, RESET_BUTTON.2, SENSOR2.1 (GND), SENSOR2.5 (SDO), SENSOR2.7 (GND), SJ1.1, TP4.TP, TP5.TP, U1.1 (GND), U1.28 (GND), U1.29_1 (GND), U1.29_2 (GND), U1.29_3 (GND), U1.29_4 (GND), U1.29_5 (GND), U1.29_6 (GND), U1.29_7 (GND), U1.29_8 (GND), U1.29_9 (GND), U2.1 (CTG), U2.4 (GND), U2.6 (QSTRT), U2.9 (EP), U3.4 (GND), U3.9 (EXP), U4.2 (VSS), U5.13 (GND)
GPIO8: R1.1, U1.10 (IO8)
I2C_PW: C23.1, C24.1, R1_PINH.2, R2-PINH.2, SENSOR2.2 (CSB), SENSOR2.6 (VDDIO), SENSOR2.8 (VDD), U1.17 (IO19)
INT_RTC: R1_PINH1.1, TP15.TP, U1.8 (IO0), U5.3 (SQW/!INT)
IO/BOOT: BOOT_BUTTON.3, BOOT_BUTTON.4, C4.1, R_BOOT.1, U1.15 (IO9)
IO/CHANGE: C5.1, CHANGE_BUTTON.3, CHANGE_BUTTON.4, R_CHANGE.1, U1.23 (IO15)
MISO: D1.2, J1.P7 (DAT0), R7.1, TP6.TP, U1.27 (IO2), U3.2 (DO(IO1))
MOSI: D2.2, J1.P3 (CMD), J3.14, R6.1, TP7.TP, U1.7 (IO7), U3.5 (DI(IO0))
unnamed: C_DELAY.1, IC1.5 (CT)
unnamed: C1_BAT1.1, D7.1 (CATHODE), IC2.1 (VIN), IC2.3 (CE), Q1.2 (S)
unnamed: CHG_LED.C, R1_BAT.1
unnamed: R1_BAT.2, U4.1 (STAT)
unnamed: R2_BAT.2, U4.5 (PROG)
unnamed: D8.1 (CATHODE), R_CAPACITOR.1
unnamed: C19.1, D9.2 (A), D11.1 (K)
unnamed: J4.A5, R2-USB1.2
unnamed: J4.B5, R2-USB.1
unnamed: EPD_C2.2, J3.5
unnamed: EPD_C1.2, J3.4
unnamed: EPD_C6.2, J3.18
unnamed: EPD_C8.2, J3.20
unnamed: EPD_C10.2, J3.22
unnamed: EPD_C7.2, J3.19
unnamed: EPD_C12.2, J3.24
PREVGH: D10.1 (K), EPD_C9.2, J3.21
PREVGL: D11.2 (A), EPD_C11.2, J3.23
RESE: J3.3, Q3.2 (S), R12.2
RESE': R9.2, R12.1, SJ1.2
RESET: C3.1, IC1.1 (VOUT), RESET_BUTTON.3, RESET_BUTTON.4, R_RESET.1, U1.3 (EN)
RTC_RST: U1.16 (IO18), U5.4 (!RST)
RX: TP2.TP, U1.24 (RXD0/GPIO17)
SCK: D3.2, J1.P5 (CLK), J3.13, R5.1, TP8.TP, U1.6 (IO6), U3.6 (CLK)
SCL: J2.4, R2-PINH.1, SENSOR2.4 (SCK), U1.20 (IO22), U2.7 (SCL), U5.16 (SCL)
SDA: J2.3, R1_PINH.1, SENSOR2.3 (SDI), U1.19 (IO21), U2.8 (SDA), U5.15 (SDA)
SRC: C19.2, D10.2 (A), L1.1, Q3.3 (D)
SS_SD: D6.2, J1.P2 (CD/DAT3), R2.1, U1.4 (IO4)
TX: TP1.TP, U1.25 (TXD0/GPIO16)
USB_D+: D12.1 (I/O1_1), U1.14 (IO13)
USB_D-: D12.3 (I/O2_1), U1.13 (IO12)
VBAT: C2_BAT.1, Q1.3 (D), TP3.TP, U2.2 (CELL), U2.3 (VDD), U4.3 (VBAT)
VBUS: C1_BAT.1, C4_USB.1, C5_USB.1, CHG_LED.A, D7.2 (ANODE), D12.5 (VBUS), PFMF.050.1.2, Q1.1 (G), R1_PWRUSB.2, TP14.TP, U4.4 (VIN)
VRTC: C8.1, C10_SUPERCAP.1, R_CAPACITOR.2, U5.14 (VBAT)
VUSB: J4.A4, J4.A9, J4.B4, J4.B9, PFMF.050.1.1

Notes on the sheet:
USB C connector & ESD protection
LDO Voltage Regulator
SD Card
ESP32 C6
Li-Po Battery Charging Controller
E-Paper Drive Circuit
Display Type Selector
E-Paper Display Header
EPD Power
Environmental Sensor BME688
Voltage Supervisor + Reset & Boot / IO Button
Battery ChargeLevel
External NORFlash64MB
SPI ESD Protection Lines
Qwiic / Stemma QT
Test Pads
RTC Module DS3231SN
drawn by: Craia Bogdan
OpenBook Schematic

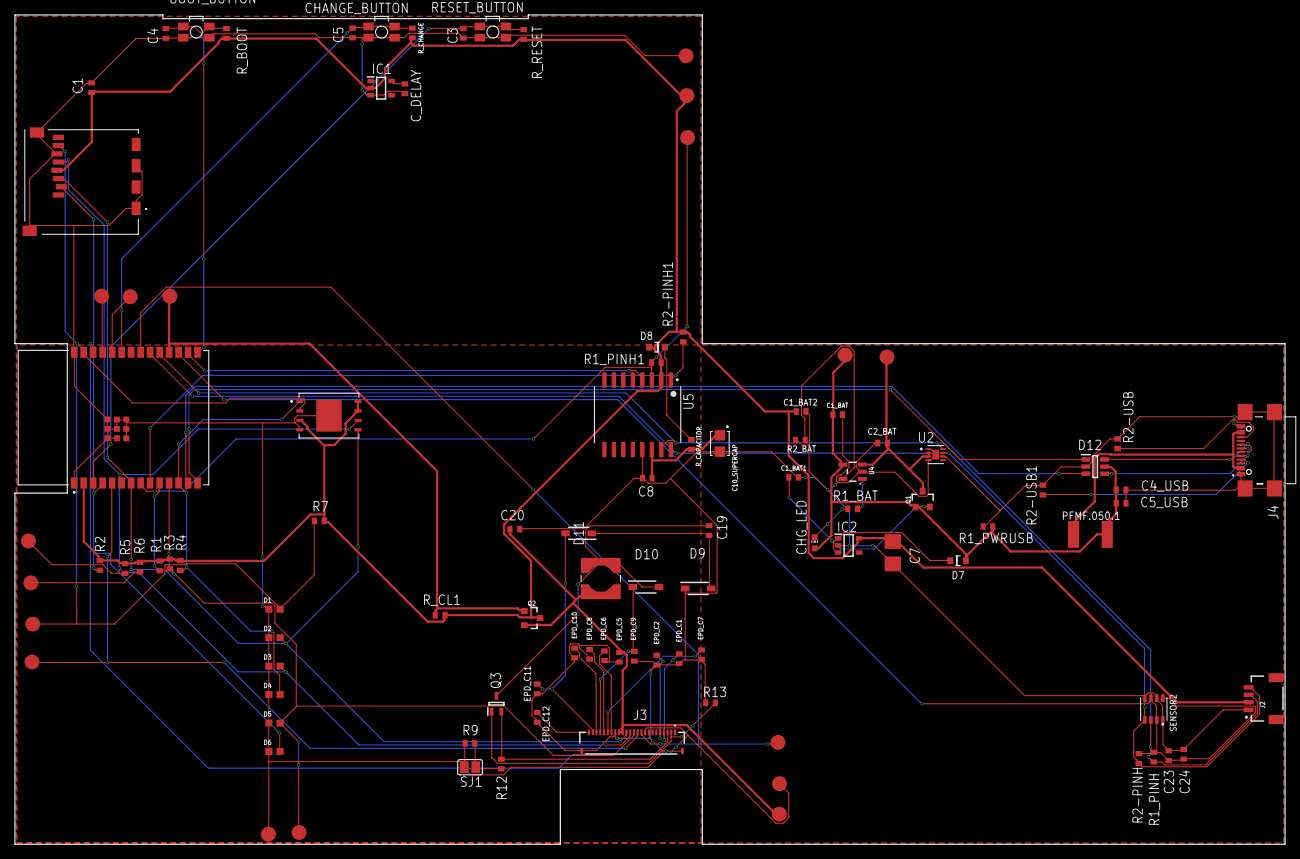
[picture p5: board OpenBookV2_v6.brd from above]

Board: 2 copper layers, 170.0 x 111.0 mm, 103 parts (0 on the bottom side), 55 nets.

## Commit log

2025-04-03 updated design
    [OpenBook Enclosure v4.f3z, OpenBook Enclosure v6.f3z, OpenBook v29.sch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]
2025-04-10 Modificare board
    [OpenBookV2_v6.brd]

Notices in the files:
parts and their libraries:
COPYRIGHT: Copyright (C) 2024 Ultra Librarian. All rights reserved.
